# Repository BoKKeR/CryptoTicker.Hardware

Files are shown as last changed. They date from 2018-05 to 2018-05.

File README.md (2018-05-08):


# Work in progress

# CryptoTicker.Hardware
CryptoTicker is an information display board that supports over 1500 coin pairs. The PCB consists of 4 individual 1.3" OLED displays controlled by an ESP32. These displays can show a coin pair each. The display outputs are shifted using a multiplexor. Updating or changing the information on the fly is possible from the localhost web server that is running on the device. Vertical and Horizontal positioning is possible. There are 4 programable push-buttons located on the back of the device.
The device can be extendable to support up to 8 displays or with extra multiplexors up to 64 displays.
# Is [coin] supported?
The full list of supported coins can be found at https://coinmarketcap.com/all/views/all/
# Where is the software?
The software is available on the second repository: https://github.com/BoKKeR/CryptoTicker.Software/
# What is missing
There will be an additional board that will be powering the CryptoTicker PCB and serving as the USB to serial converter for the EPS32. There are smaller problems with this design. The files will be updated soon.
# Schematics
Schematics
# PCB Design
PCB Design
# BOM
Incoming
Open source hardware design

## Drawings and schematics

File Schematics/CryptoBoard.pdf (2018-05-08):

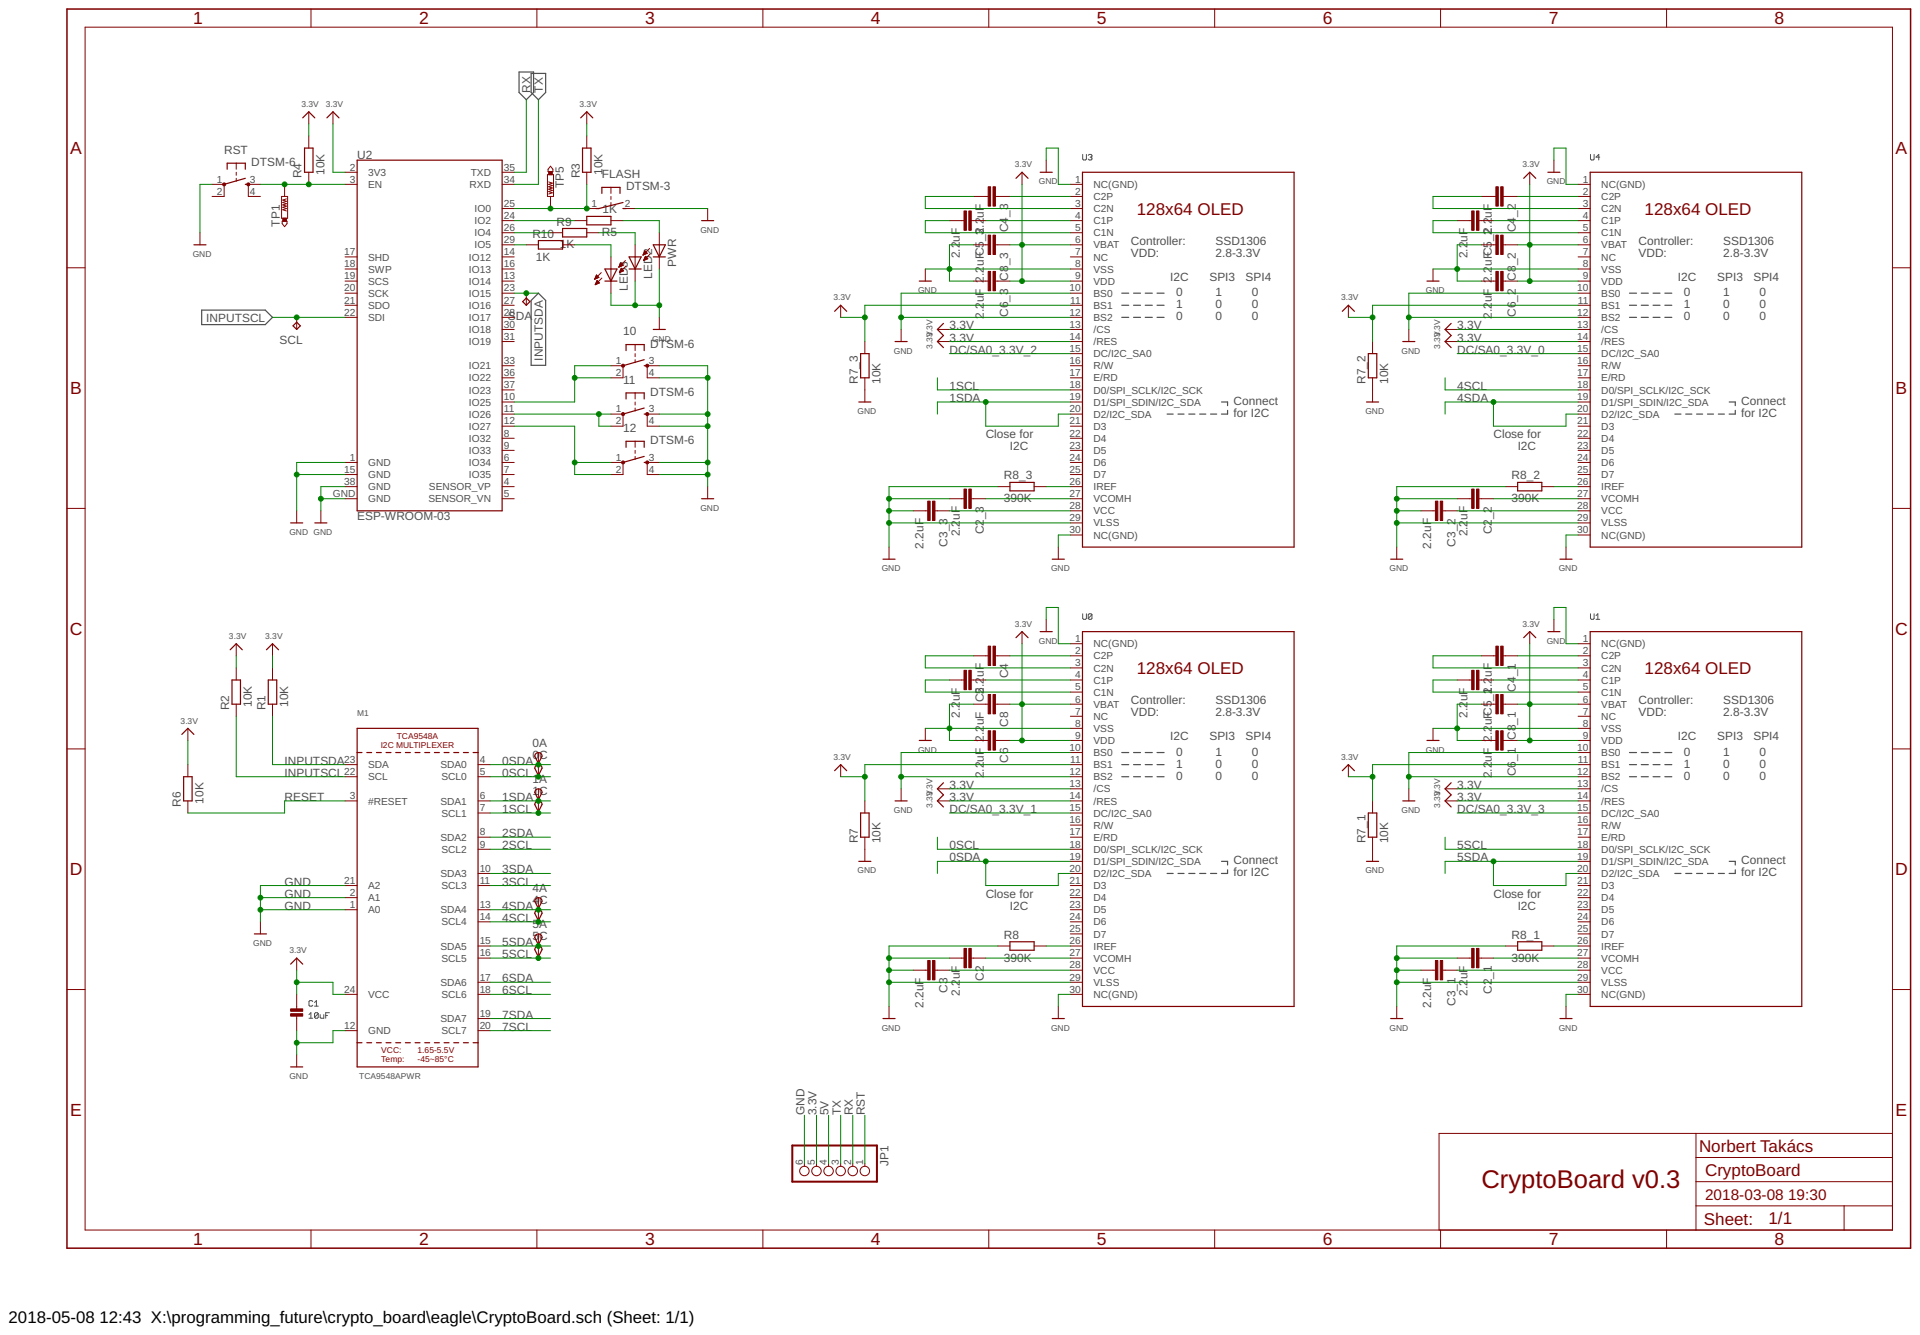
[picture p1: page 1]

2018-05-08 12:43 X:\programming_future\crypto_board\eagle\CryptoBoard.sch (Sheet: 1/1)

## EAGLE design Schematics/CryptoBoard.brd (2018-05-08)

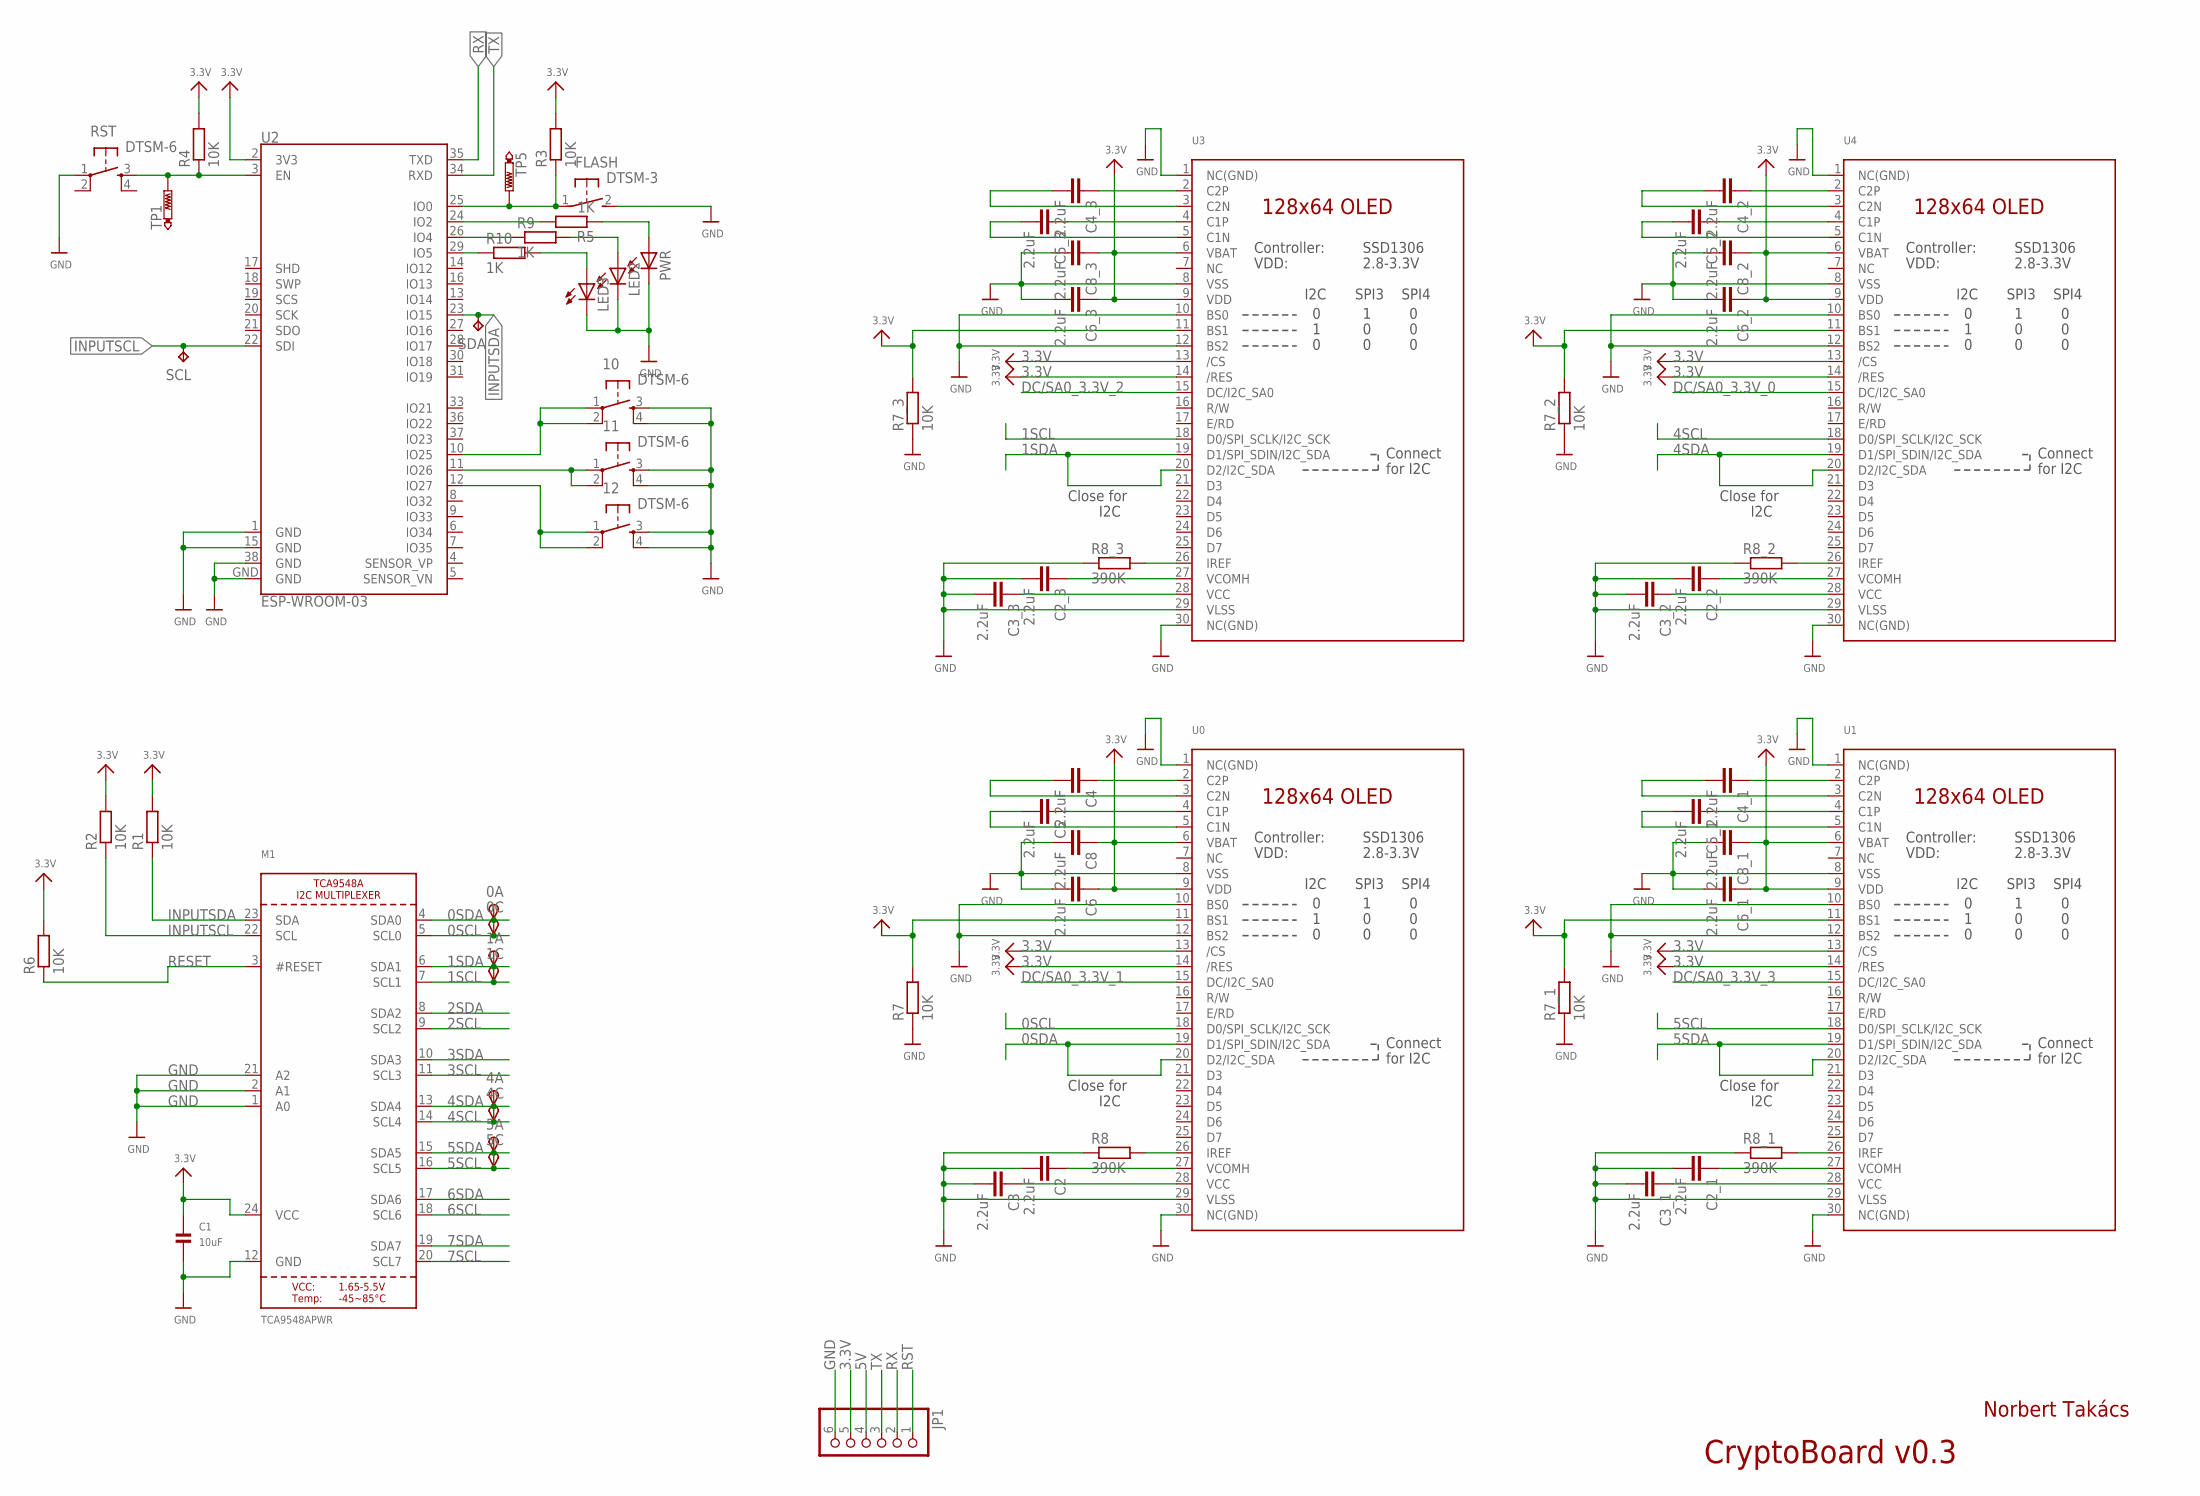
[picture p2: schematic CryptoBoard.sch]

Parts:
0A, 0C, 1A, 1C, 4A, 4C, 5A, 5C: TPSTP20R; TP20R
10, 11, 12: DTSM-6
C1: 10uF; 0805
C2, C2_1, C2_2, C2_3, C3, C3_1, C3_2, C3_3, C4, C4_1, C4_2, C4_3, C5, C5_1, C5_2, C5_3, C6, C6_1, C6_2, C6_3, C8, C8_1, C8_2, C8_3: 2.2uF; C0805
FLASH: DTSM-3
JP1: PINHD-1X6; 1X06
LED2, LED3: LEDSML0805; SML0805
M1: TCA9548APWR; TSSOP24
PWR: LEDSML0805; SML0805
R1, R2, R3, R4, R6, R7, R7_1, R7_2, R7_3: 10K; M0805
R5, R9, R10: 1K; M0805
R8, R8_1, R8_2, R8_3: 390K; M0805
RST: DTSM-6
SCL: TPPAD1-13; P1-13
SDA: TPPAD1-13; P1-13
TP1, TP5: PTR1B2,54; B2,54
U0, U1, U3, U4: DISP_OLED_UG-2864HSWEG01; UG-2864HSWEG01_1.3_WRAPAROUND
U2: ESP-WROOM-03

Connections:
0SCL: 0C.TP, M1.5 (SCL0), U0.18 (D0/SPI_SCLK/I2C_SCK)
0SDA: 0A.TP, M1.4 (SDA0), U0.19 (D1/SPI_SDIN/I2C_SDA), U0.20 (D2/I2C_SDA)
1SCL: 1C.TP, M1.7 (SCL1), U3.18 (D0/SPI_SCLK/I2C_SCK)
1SDA: 1A.TP, M1.6 (SDA1), U3.19 (D1/SPI_SDIN/I2C_SDA), U3.20 (D2/I2C_SDA)
2SCL: M1.9 (SCL2)
2SDA: M1.8 (SDA2)
3.3V: C1.1, C6.1, C6_1.1, C6_2.1, C6_3.1, C8.1, C8_1.1, C8_2.1, C8_3.1, JP1.5, M1.24 (VCC), R1.2, R2.2, R3.2, R4.2, R6.2, R7.2, R7_1.2, R7_2.2, R7_3.2, U0.6 (VBAT), U0.9 (VDD), U0.11 (BS1), U0.13 (/CS), U0.14 (/RES), U1.6 (VBAT), U1.9 (VDD), U1.11 (BS1), U1.13 (/CS), U1.14 (/RES), U2.2 (3V3), U3.6 (VBAT), U3.9 (VDD), U3.11 (BS1), U3.13 (/CS), U3.14 (/RES), U4.6 (VBAT), U4.9 (VDD), U4.11 (BS1), U4.13 (/CS), U4.14 (/RES)
3SCL: M1.11 (SCL3)
3SDA: M1.10 (SDA3)
4SCL: 4C.TP, M1.14 (SCL4), U4.18 (D0/SPI_SCLK/I2C_SCK)
4SDA: 4A.TP, M1.13 (SDA4), U4.19 (D1/SPI_SDIN/I2C_SDA), U4.20 (D2/I2C_SDA)
5SCL: 5C.TP, M1.16 (SCL5), U1.18 (D0/SPI_SCLK/I2C_SCK)
5SDA: 5A.TP, M1.15 (SDA5), U1.19 (D1/SPI_SDIN/I2C_SDA), U1.20 (D2/I2C_SDA)
5V: JP1.4
6SCL: M1.18 (SCL6)
6SDA: M1.17 (SDA6)
7SCL: M1.20 (SCL7)
7SDA: M1.19 (SDA7)
DC/SA0_3.3V_0: U4.15 (DC/I2C_SA0)
DC/SA0_3.3V_1: U0.15 (DC/I2C_SA0)
DC/SA0_3.3V_2: U3.15 (DC/I2C_SA0)
DC/SA0_3.3V_3: U1.15 (DC/I2C_SA0)
GND: 10.3, 10.4, 11.3, 11.4, 12.3, 12.4, C1.2, C2.2, C2_1.2, C2_2.2, C2_3.2, C3.2, C3_1.2, C3_2.2, C3_3.2, C6.2, C6_1.2, C6_2.2, C6_3.2, C8.2, C8_1.2, C8_2.2, C8_3.2, FLASH.2, JP1.6, LED2.C, LED3.C, M1.1 (A0), M1.2 (A1), M1.12 (GND), M1.21 (A2), PWR.C, R7.1, R7_1.1, R7_2.1, R7_3.1, R8.1, R8_1.1, R8_2.1, R8_3.1, RST.1, U0.1 (NC(GND)), U0.8 (VSS), U0.10 (BS0), U0.12 (BS2), U0.29 (VLSS), U0.30 (NC(GND)), U1.1 (NC(GND)), U1.8 (VSS), U1.10 (BS0), U1.12 (BS2), U1.29 (VLSS), U1.30 (NC(GND)), U2.1 (GND), U2.15 (GND), U2.38 (GND), U2.GND, U3.1 (NC(GND)), U3.8 (VSS), U3.10 (BS0), U3.12 (BS2), U3.29 (VLSS), U3.30 (NC(GND)), U4.1 (NC(GND)), U4.8 (VSS), U4.10 (BS0), U4.12 (BS2), U4.29 (VLSS), U4.30 (NC(GND))
INPUTSCL: M1.22 (SCL), R2.1, SCL.TP, U2.22 (SDI)
INPUTSDA: M1.23 (SDA), R1.1, SDA.TP, U2.23 (IO15)
unnamed: 10.1, 10.2, U2.10 (IO25)
unnamed: R8.2, U0.26 (IREF)
unnamed: C4.1, U0.2 (C2P)
unnamed: C4.2, U0.3 (C2N)
unnamed: C5.1, U0.4 (C1P)
unnamed: C5.2, U0.5 (C1N)
unnamed: R8_3.2, U3.26 (IREF)
unnamed: C3.1, U0.28 (VCC)
unnamed: C2.1, U0.27 (VCOMH)
unnamed: C4_3.1, U3.2 (C2P)
unnamed: C4_3.2, U3.3 (C2N)
unnamed: C5_3.1, U3.4 (C1P)
unnamed: C5_3.2, U3.5 (C1N)
unnamed: C3_3.1, U3.28 (VCC)
unnamed: C2_3.1, U3.27 (VCOMH)
unnamed: R8_1.2, U1.26 (IREF)
unnamed: C4_1.1, U1.2 (C2P)
unnamed: C4_1.2, U1.3 (C2N)
unnamed: C5_1.1, U1.4 (C1P)
unnamed: C5_1.2, U1.5 (C1N)
unnamed: R8_2.2, U4.26 (IREF)
unnamed: C4_2.1, U4.2 (C2P)
unnamed: C4_2.2, U4.3 (C2N)
unnamed: C5_2.1, U4.4 (C1P)
unnamed: C5_2.2, U4.5 (C1N)
unnamed: C3_2.1, U4.28 (VCC)
unnamed: C2_2.1, U4.27 (VCOMH)
unnamed: C3_1.1, U1.28 (VCC)
unnamed: C2_1.1, U1.27 (VCOMH)
unnamed: PWR.A, R5.1
unnamed: R9.1, U2.26 (IO4)
unnamed: FLASH.1, R3.1, TP5.TP, U2.25 (IO0)
unnamed: R5.2, U2.24 (IO2)
unnamed: 11.1, 11.2, U2.11 (IO26)
unnamed: 12.1, 12.2, U2.12 (IO27)
unnamed: LED2.A, R9.2
unnamed: LED3.A, R10.2
unnamed: R10.1, U2.29 (IO5)
RESET: M1.3 (#RESET), R6.1
RST: JP1.1
RX: JP1.2, U2.35 (TXD)
SHORT: R4.1, RST.3, TP1.TP, U2.3 (EN)
TX: JP1.3, U2.34 (RXD)

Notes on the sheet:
Close for
I2C
Norbert Takács
CryptoBoard v0.3

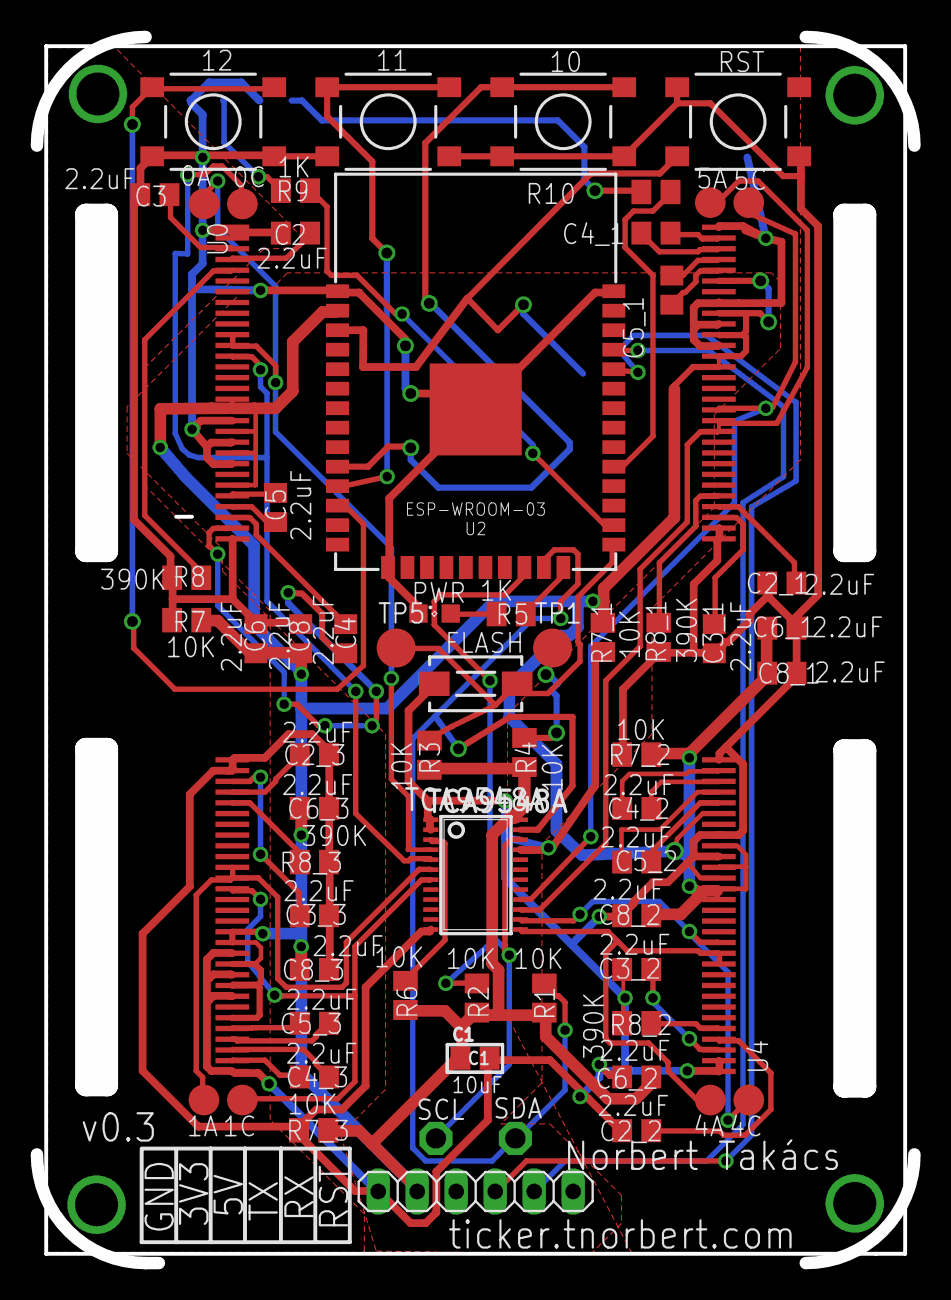
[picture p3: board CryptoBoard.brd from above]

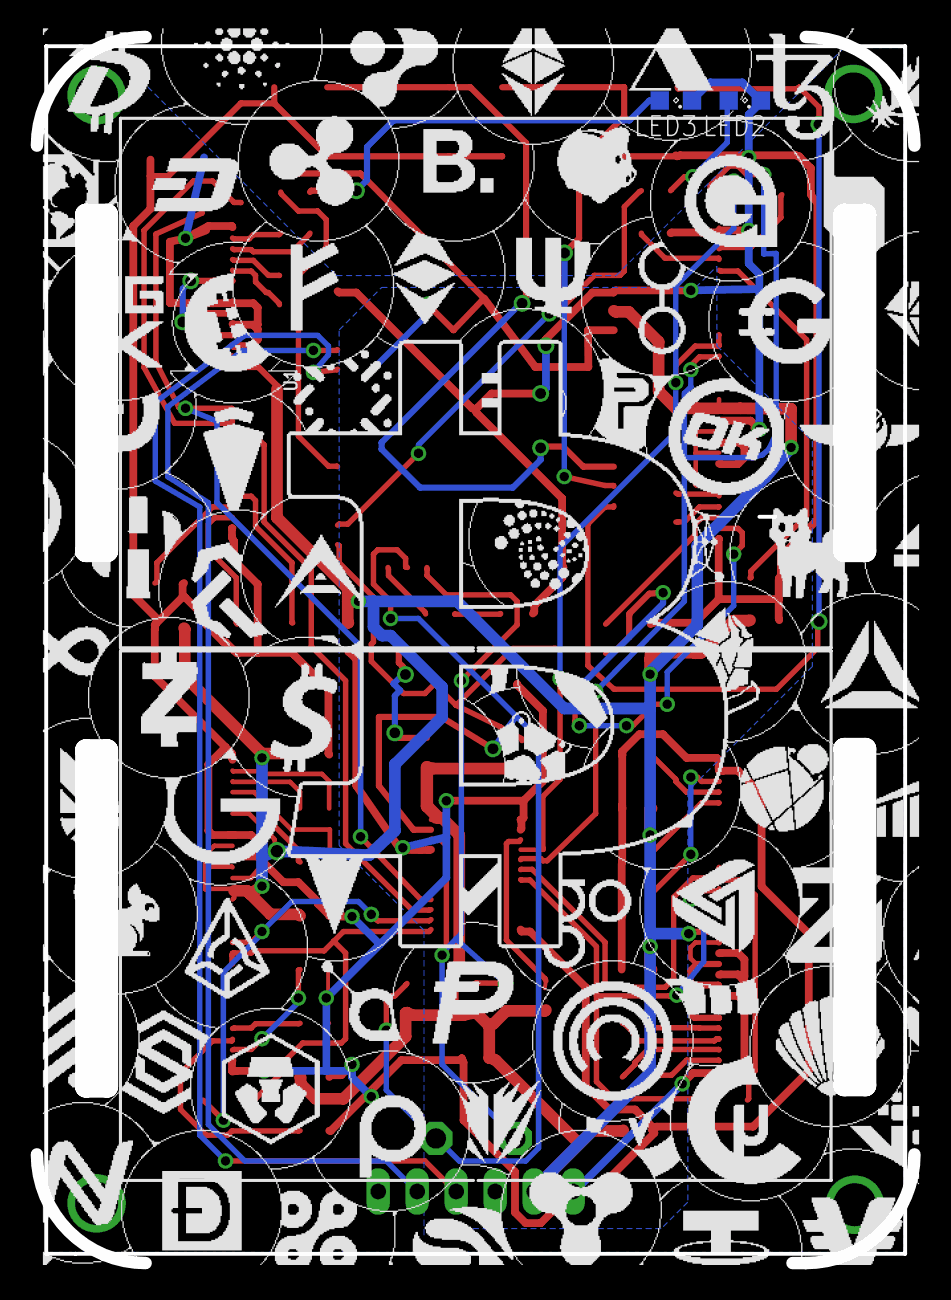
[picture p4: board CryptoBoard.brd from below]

Board: 2 copper layers, 57.2 x 79.9 mm, 68 parts (6 on the bottom side), 54 nets.

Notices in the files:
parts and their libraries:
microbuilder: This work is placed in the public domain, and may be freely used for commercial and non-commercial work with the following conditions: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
